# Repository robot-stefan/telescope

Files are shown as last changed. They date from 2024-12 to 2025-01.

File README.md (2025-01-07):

# Telescope
A 3d printed newtonian telescope I designed and built as a personal project. 
Some quick highlights: 
-	the unit features baffling down the optical tube assembly
-	can be printed in the volume of a Prusa MK3S or similarly sized printer
-	is modular in construction allowing for disassembly

> Note: If anyone is interested in a kit or having the prints shipped to them, feel free to contact me and I'll look into pricing. 

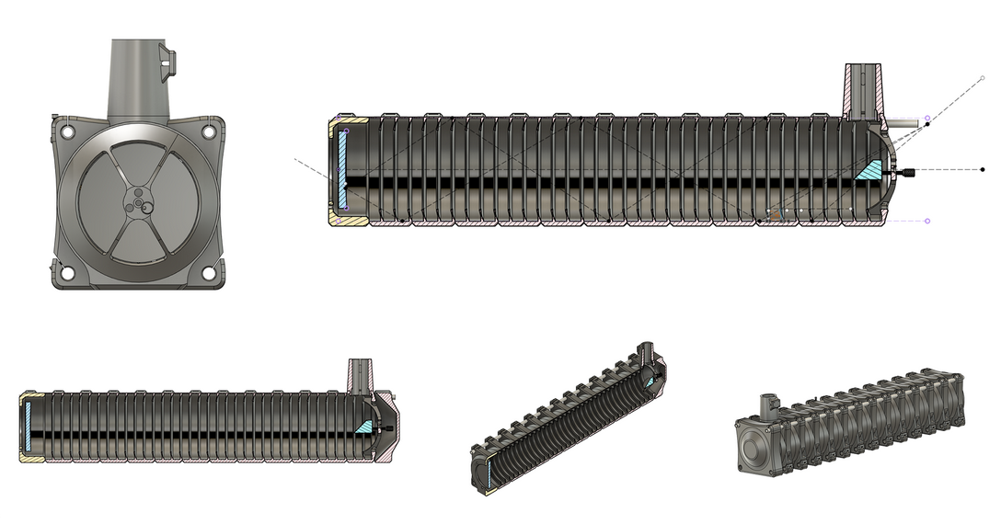
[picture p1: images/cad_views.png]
screenshot_of_various_CAD_views


## Design
Autodesk Fusion 360 was used as the CAD[^CAD] tool and Prusa Slicer served as the CAM[^CAM] tool in the development process. The design was started with 2D high level sketching exploring mirror, lens, and ray paths to drive posistioning of the key parts. Once this phase was completed the structure was iterated on. The slicer acted as a feedback mechanism allowing for the design to be adjusted not only for use, and assembly, but also for ease of printing. Ease of printing in this sense meaning optimizing the filament use of each section so that there is no need to swap out rolls during printing (if starting with a full roll) and that the supports would be easy to remove. It can be noted that depending on a shape a support can take a non-trivial time to remove, and that its removal could also result in damaging the print. Optical components (mirrors, lenses, and mounts) were sourced from Amazon while raw material & hardware from McMaster-Carr. A simple BoM[^BoM] can be found in the [models/README.md](models/README.md).

Flow chart of the Design Process:
```mermaid
graph TD;
    CAD-AutodeskFusion360-->CAM-PrusaSlicer;
    CAM-PrusaSlicer-->CAD-AutodeskFusion360;
    CAM-PrusaSlicer-->3dPrinter;
    Concept-->CAD-AutodeskFusion360;
    3dPrinter-->TestParts;
    TestParts-->CAD-AutodeskFusion360;
    TestParts-->CAM-PrusaSlicer;
    TestParts-->EndPoint;
```

### Baffles
Each cross section is printed with ridges/fingers/ribs. These are baffles and they act to trap stray light rays or reduce the energy in the stray light ray by bouncing it around some before it gets to a person’s eye or a camera / imager. You can see some rough sketches that were turned on where ray tracing was done manually to find a good enough configuration in the below image. 

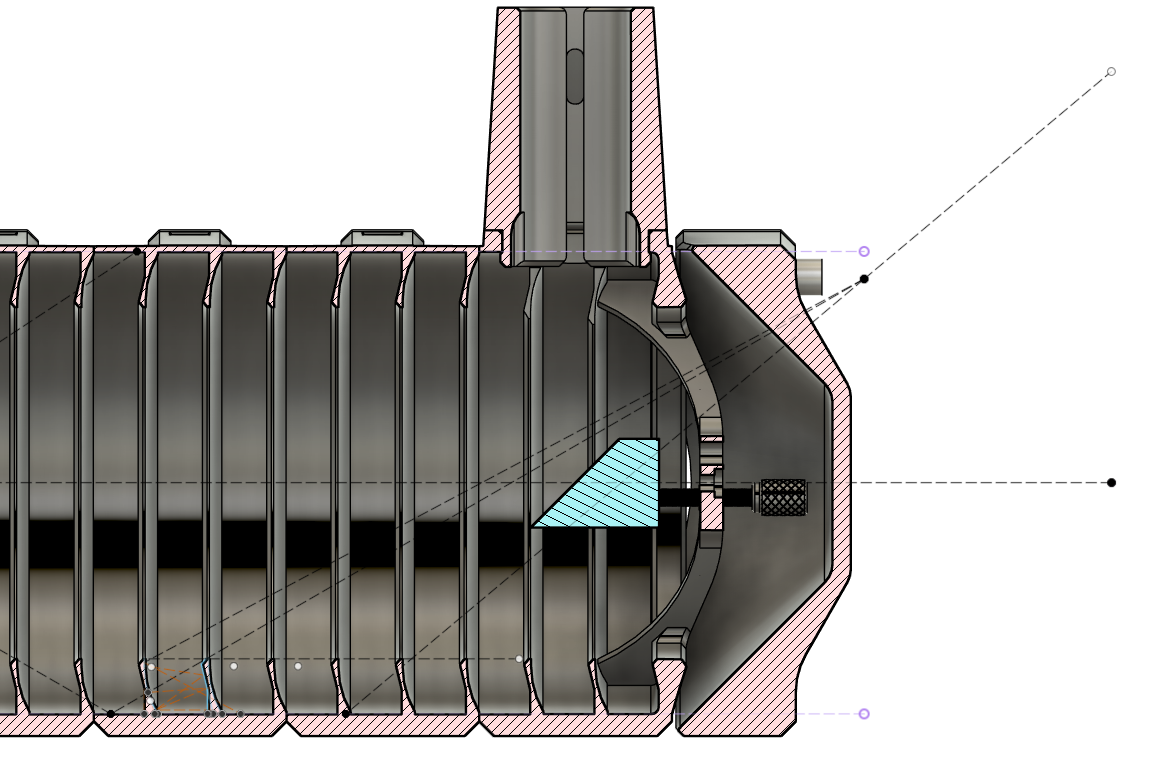
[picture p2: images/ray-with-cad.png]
image_of_manual_raytrace


These rays could come from artificial light sources and other sources that might impact image quality. Telescope builds in this size class are typically done with plain cardboard tubes which are then coated with a matte black paint. The approach lowers the amount of reflected energy, but depending on the ray incident with the tube wall light may only have one or two bounces. Since this was 3D printed, I had the ability to go beyond a plain tube and add additional complexity in the form of baffling. These baffles function to trap rays giving them 2 or more bounces before leaving the baffle reducing ray energy. Ideally these baffles would also be coated with a low reflective paint for added performance. If one were to fully optimize the baffles these features would change spacing and geometry (curve profile) through the length of the tube assembly [^MERTIS]. However, to keep the part variation low, all tube cross sections (except for the front and rear) are the same. As I am located in a urban area baffleing can mitigate nearish light sources such as street lights, flashlights, illumination from mobile devices, and automotive sources. A closer look at the baffles can be found in [analysis/README.md](analysis/README.md).

### Printing
The parts are printed with less supports that normally seen due to tweaks in geometry[^FdmDesignGuide]. Supports were manually added in a few spots. The telescope was constrained in size by what I could fit standing up on the printer. All sections (except for the eye piece are a single print). The eye piece end is printed in two parts and bonded together.  Removing the tube and having it glued in allowed for build test and design iterations that did not need to wait on an 18 hr print, also reduced filament consumption, and allowed for test prints in between the batch prints of the other sections. The tube which holds the eye piece required some iterations to get the right amount of friction in the adjustment for the eye piece. 
Very low gyroid infills were used and supports were manually added to improve support removal and print time. 

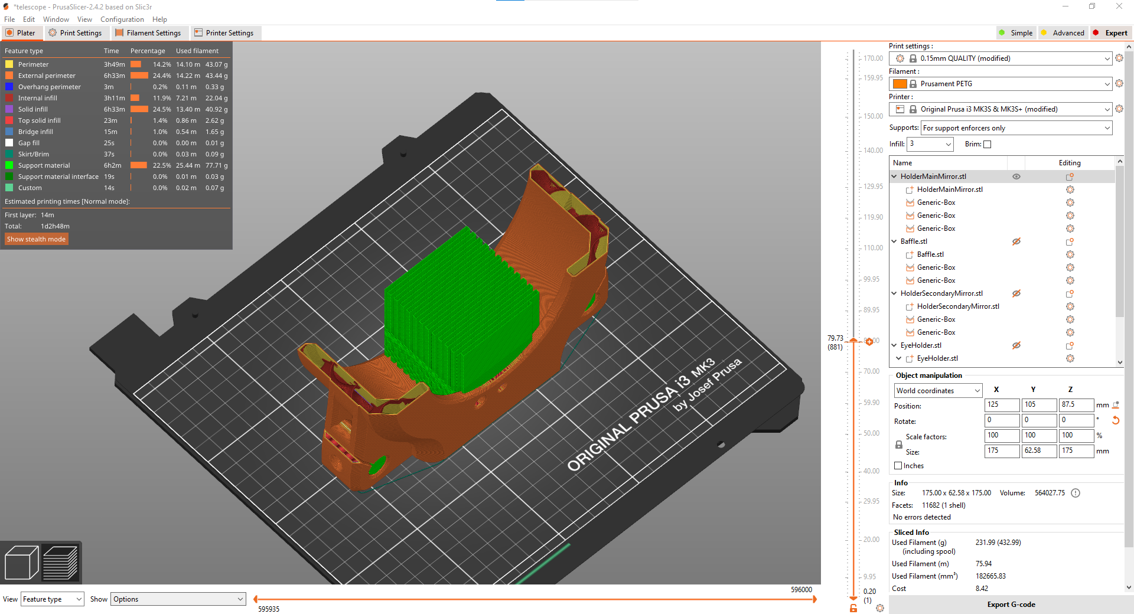
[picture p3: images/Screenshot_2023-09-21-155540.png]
screenshot_of_prusa_slicer


## Disassembly & Reassembly 
One of the driving goals of the modularity was to allow the unit to be broken down to fit with in the standard airline checked luggage size limit (with the optics being carry on). The closest darksies with minimal treecover are all west of the Mississippi River[^DarkSkyMap]. Theses sites would necessitate a long road trip or flying. 
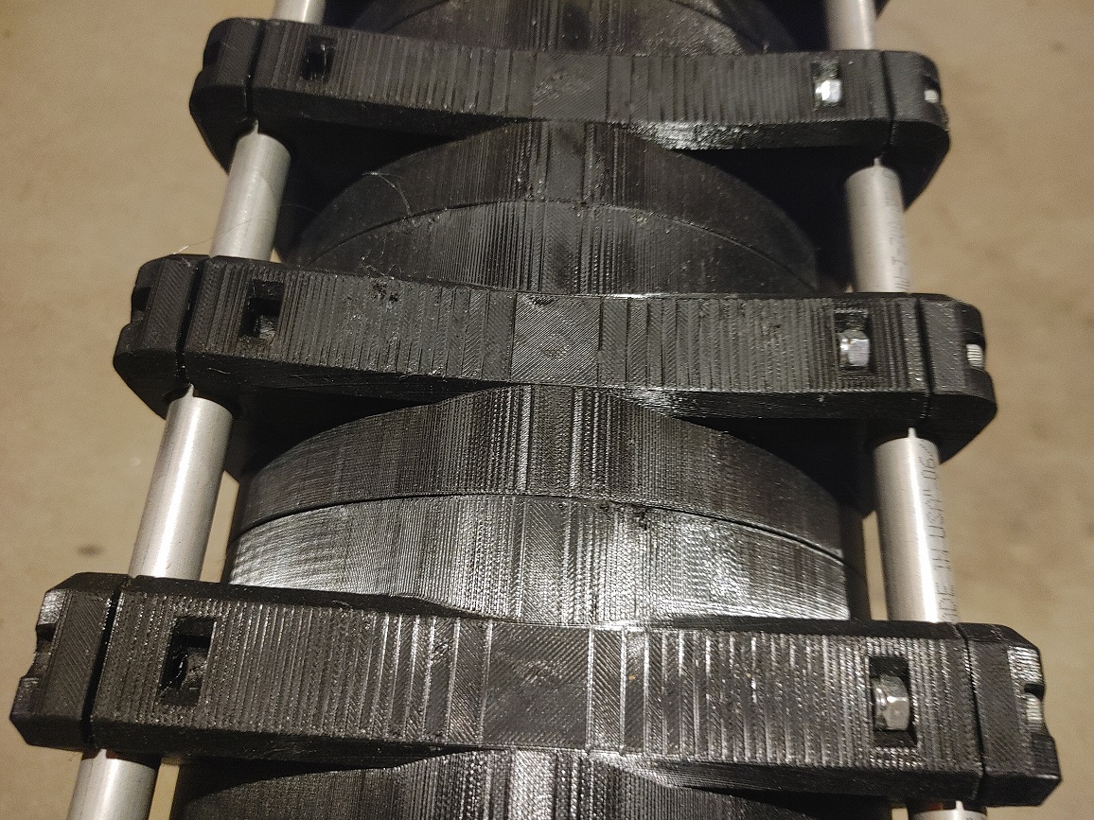
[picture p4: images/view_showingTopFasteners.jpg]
view_of_top_fasteners

For assembly and dissassembly time not all locations for fastners were utilized. It was found that the pockets for the nuts were a bit thin. Switching to non nylocs or thicker walls in these regions would remedy this. 

## Using the Telescope
### First Light
Some of the 1st images captured with a cell phone and camera mount. More work can be done to improve this such as getting an imager board and more ridigly mounting a camera to the scope. Currently taking photos of stars is not possible. The picture of jupiter is a near best case of these results using a smart phone camera. The COTS phone mount I found is not good enough for sufficently large cell phones. A fair bit of detail can be seen with the eye including a few of the moons of jupiter. The below photos were taken in suburban metro Atlanta, GA. 

| Jupiter | Moon 1 | Moon 2 |
| :---: | :---: | :---: |
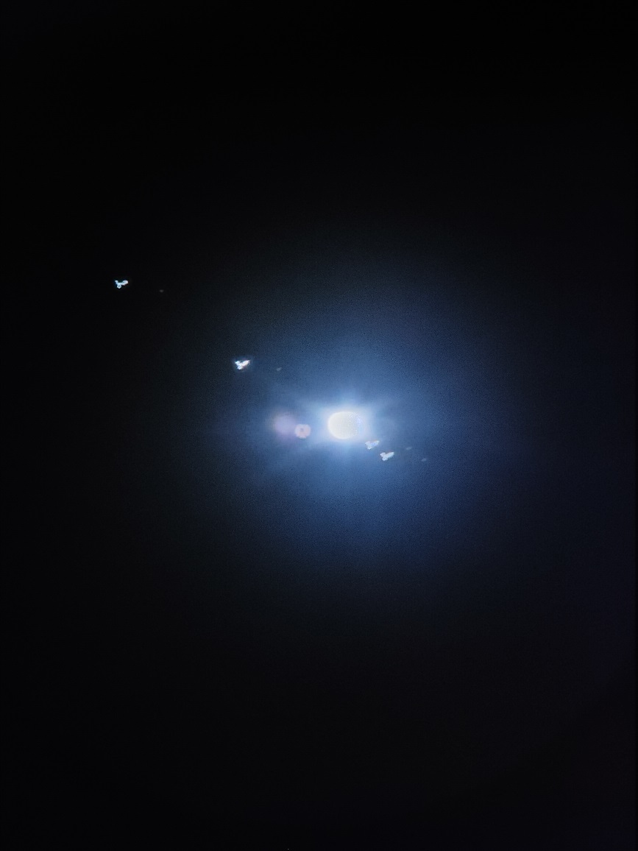
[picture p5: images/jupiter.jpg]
image_of_jupiter
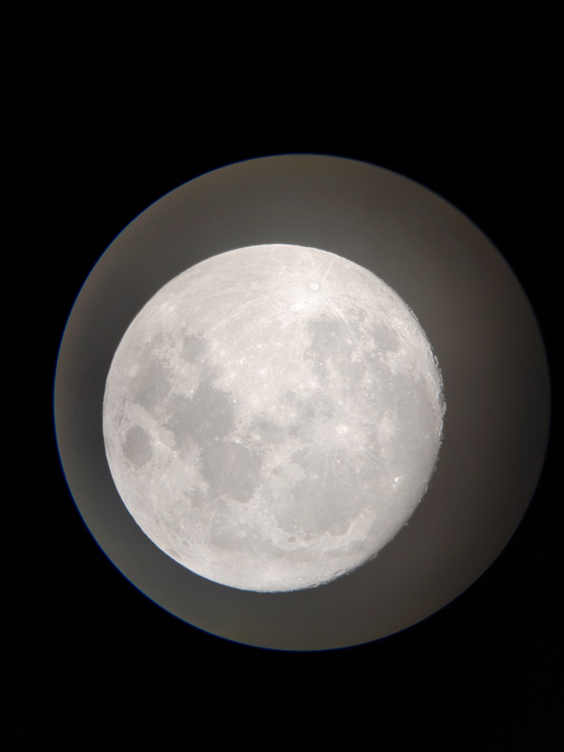
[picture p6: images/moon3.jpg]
image_of_moon
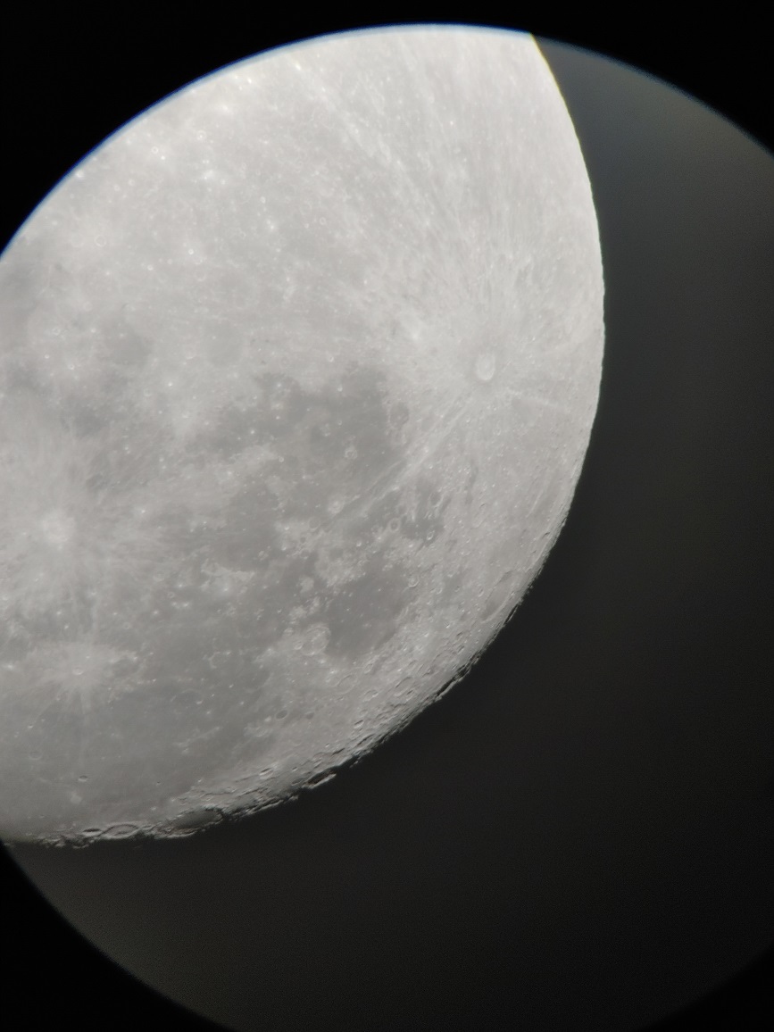
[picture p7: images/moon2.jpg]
image_of_moon
|  |  |  |

At present the unit does not have a finder scope to aim to help with aiming. The inward curved sides can be used with some success to aim at targets. This along with the cell phone mounting is a current short coming of the system. A finder scope may be added in the future. The rails running along each corner were exposed in the design to allow for adding attachments. The adapter to attach to a tripod was connected to the telescope with the rails. 

### Camping Trip
I was able to do a camping trip out to Camanche National Grasslands[^Comanche] as part of road trip to Denver for a trade show. A number of sites in the grasslands feature very dark skies and minimal tree or tall terrain features providing a near unobstructed full 360 degree view of the sky in some of the darkest areas of the continental United States. No photos from the scope exist due to issues with the COTS phone mount. 

| Deploying System | Image of Sky | Telescope Setup @ Night |
| :---: | :---: | :---: |
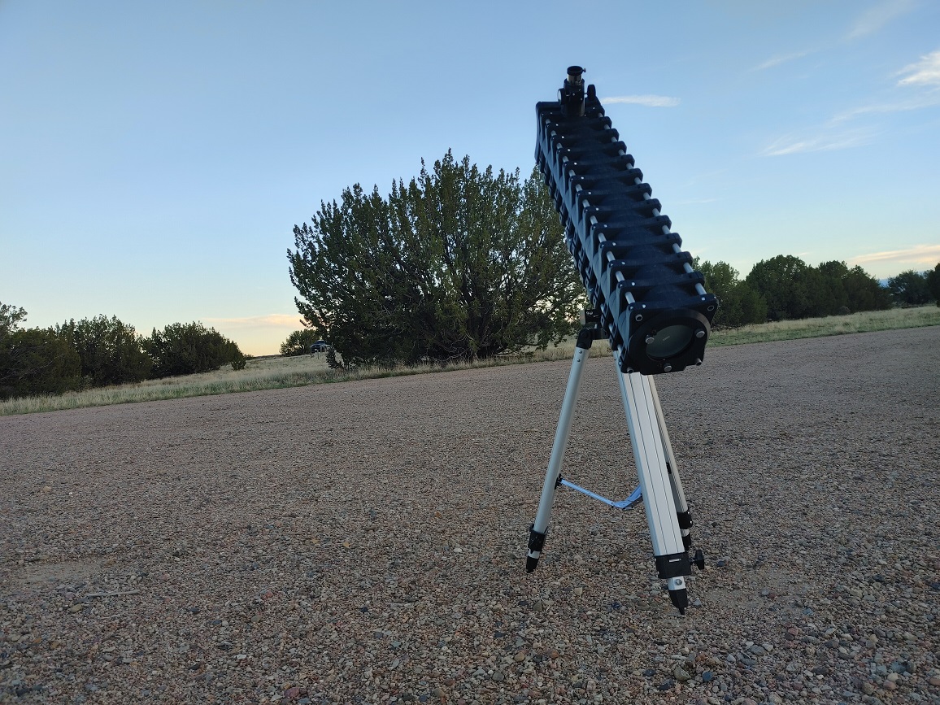
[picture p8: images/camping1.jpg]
image_of_camping_setup_in_daylight
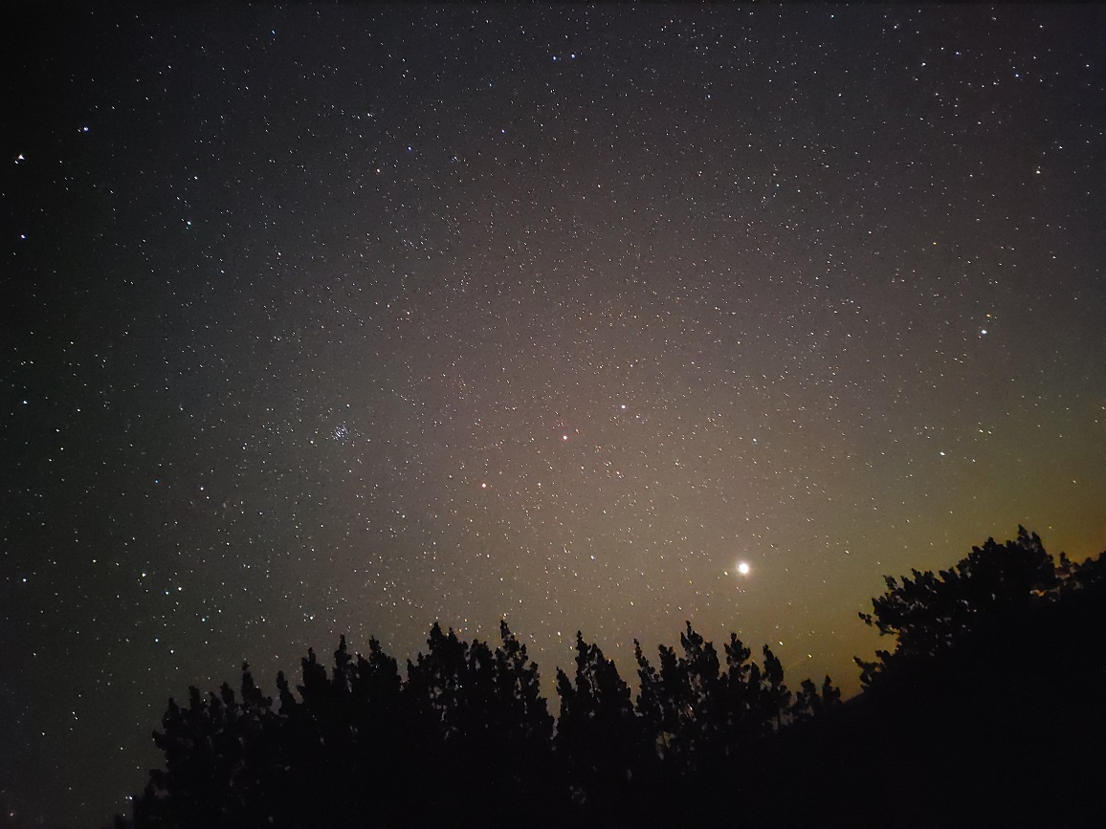
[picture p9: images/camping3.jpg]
image_of_sky
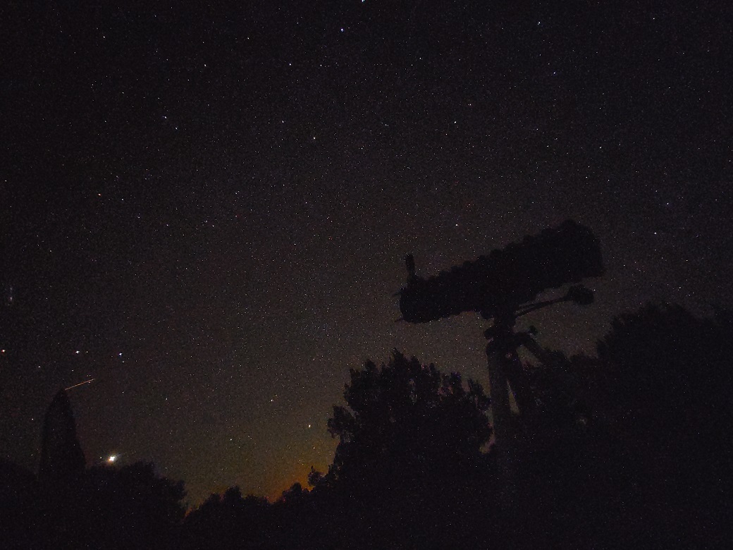
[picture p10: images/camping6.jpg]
image_of_telesope at night
|  |  |  |

[^CAD]: CAD = Computer Aided Design 
[^CAM]: CAM = Computer Aided Machining / Manufacturing
[^BoM]: BoM = Bill of Materials
[^MERTIS]: [MERTIS - Reflective baffle design and manufacturing](https://www.nicoform.com/Images_Content/Site1/Files/Articles/MERTISReflectiveBaffleDesign.pdf)
[^DarkSkyMap]: [Dark Sky Map](https://www.darkskymap.com/)
[^Comanche]: [Comanche National Grasslands](https://www.fs.usda.gov/recarea/psicc/recarea/?recid=12409)
[^FdmDesignGuide]: [FDM 3d Printing Design Guide](https://www.hubs.com/knowledge-base/how-design-parts-fdm-3d-printing/)

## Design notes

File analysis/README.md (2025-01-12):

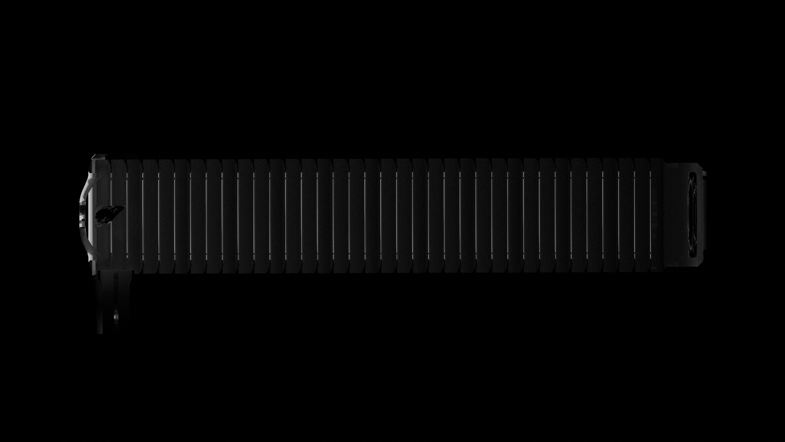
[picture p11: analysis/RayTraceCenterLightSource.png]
image_of_raytrace_OLF_B


In the overview it was mentioend that the baffle design was done with manual geometric ray tracing in the top level sketches of the cad file. The overall approach was inspire by the MERTIS paper (ref is in the primary README). There are limitations to the manual approach, but how good or good enough is it? 

While opensource ray tracing and optics design tools are not as well polished as commercial tools such as tracepro and zemax, there are options to look at the baffle design with ray tracing found in opensource rendering software. This approach can give us a comparison, but cannot give us exact info such as an easy way to observe the path of rays, energy in the rays, or a route to numerically compare the results. A qualitative and some what subjective approach can be attempted with tools such as Blender[^1] and LuxCoreRender[^2]. 

Blender 4.2 and BlendLuxCore 2.9 were used on windows to conduct this comparison. The render time was fixed and plain tube was swapped out the baffle sections. Material properties with a matte finish and lighting setup was kept the same so that the only variable in each is the geometry. The secondary mirror was also turned off.

| Setup | Baffle | Plain |
| :---: | :---: | :---: |
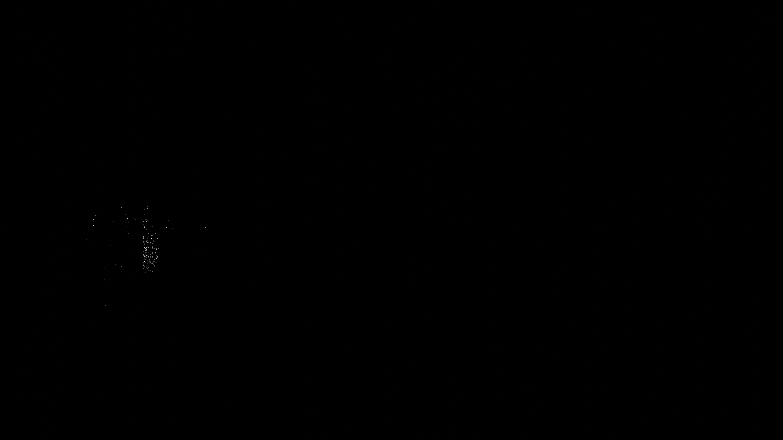
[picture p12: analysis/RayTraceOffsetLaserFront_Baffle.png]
image_of_raytrace_OLF_B
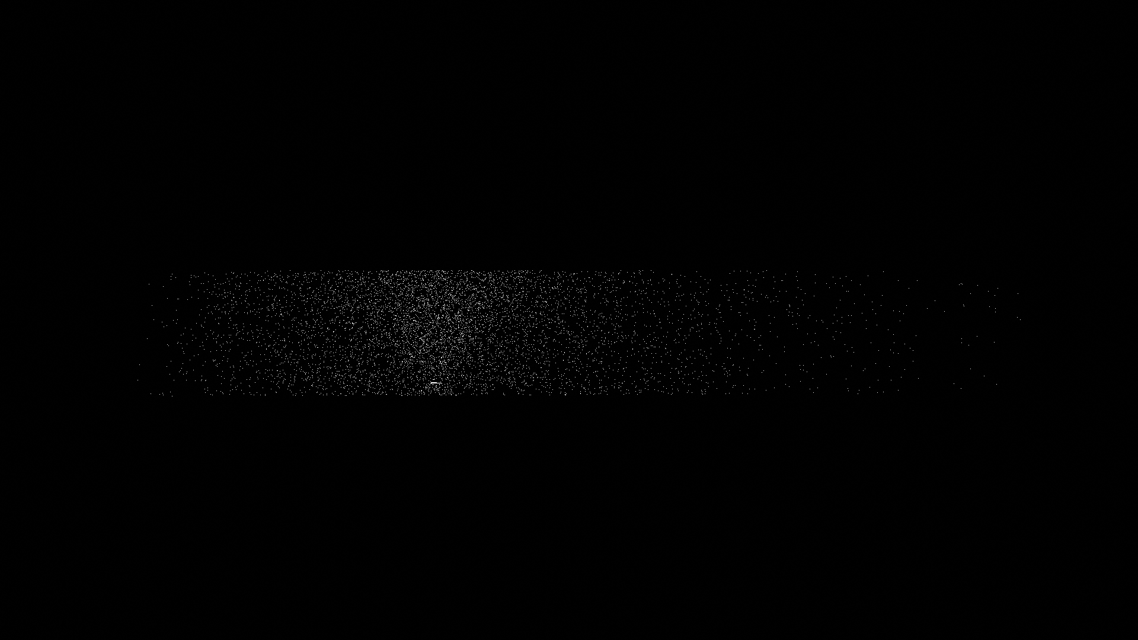
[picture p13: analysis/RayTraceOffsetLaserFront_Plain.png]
image_of_raytrace_OLF_P
| Offset Laser Front |  |  |
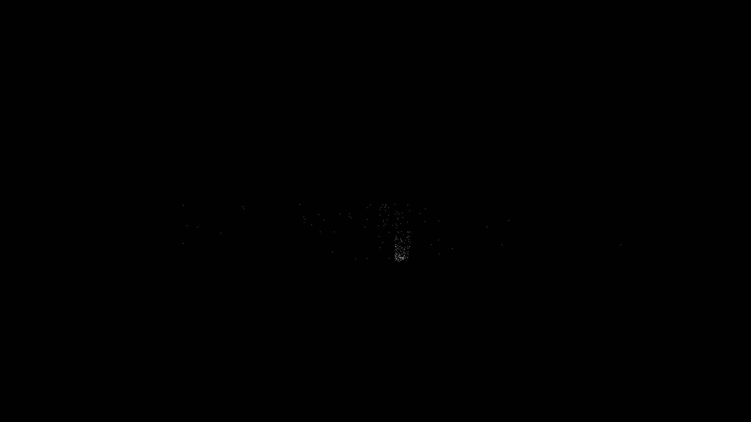
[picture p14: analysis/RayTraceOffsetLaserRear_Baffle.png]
image_of_raytrace_OLR_B
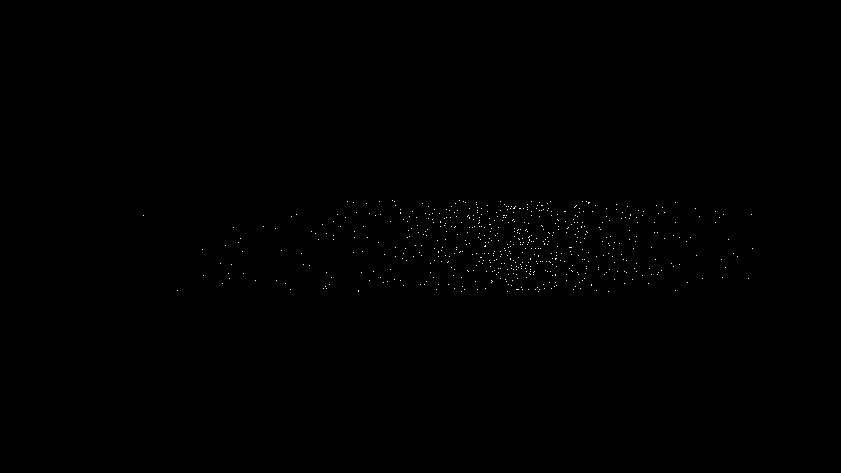
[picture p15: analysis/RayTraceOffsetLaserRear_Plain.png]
image_of_raytrace_OLR_P
| Offset Laser Rear | |  |
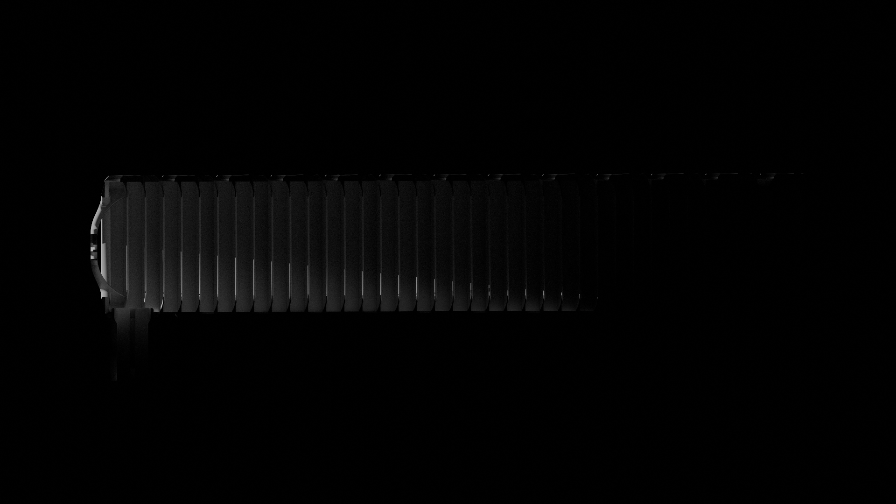
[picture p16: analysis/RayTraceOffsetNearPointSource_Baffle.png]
image_of_raytrace_ONPS_B
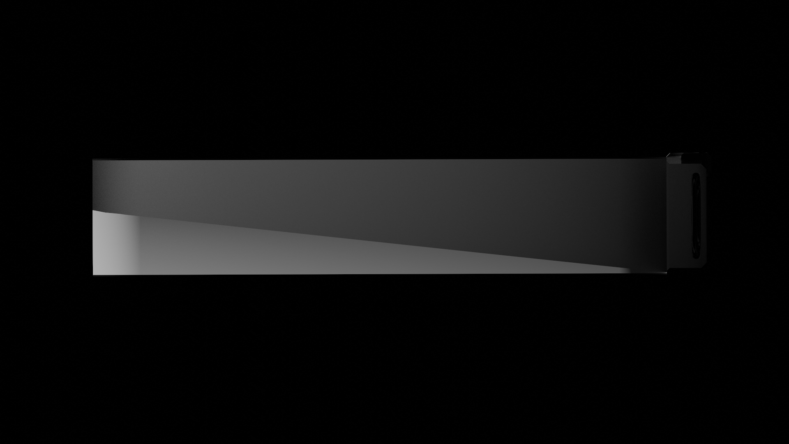
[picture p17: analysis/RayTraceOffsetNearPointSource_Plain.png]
image_of_raytrace_ONPS_P
| Offset Point Near|  |  |
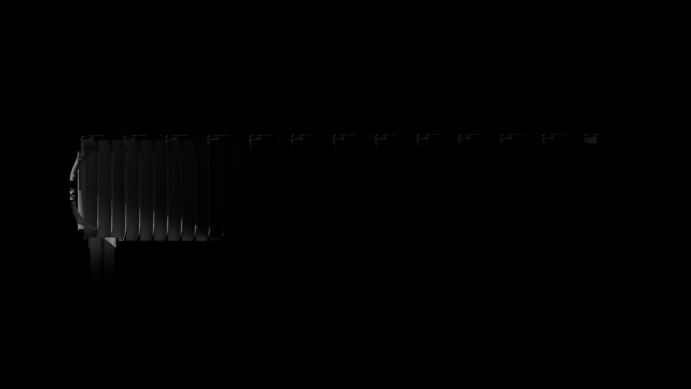
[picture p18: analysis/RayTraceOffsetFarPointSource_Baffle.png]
image_of_raytrace_OFPS_B
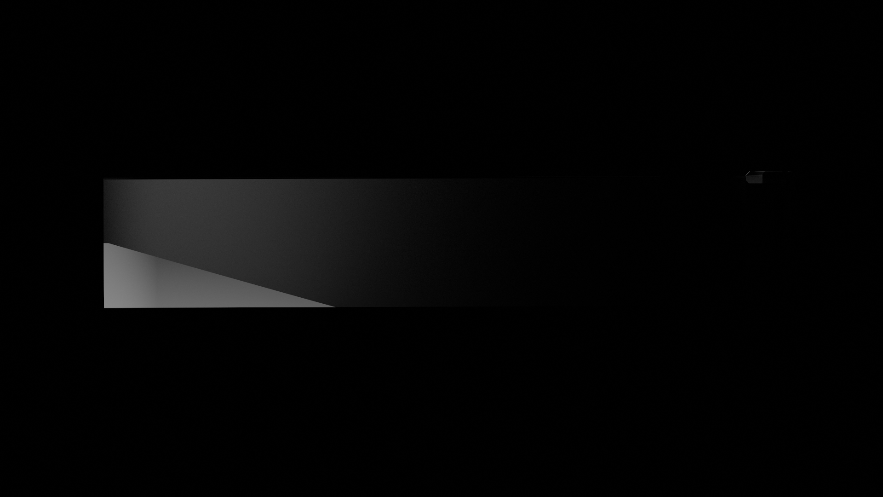
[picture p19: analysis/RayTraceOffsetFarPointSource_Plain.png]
image_of_raytrace_OFPS_P
| Offset Point Far|  |  |

Looking at the two laser setups we can see that the baffles do appear to be trapping reflections as generally intended compared to the tube. For the offset point sources we can also observe that the baffled tube seems to be greatly reducing the light energy that gets down toward the primary mirror compared to the plain tube. Thus reducing stray light rays getting to the eye piece. One area of improvement can be somewhat observed in the offset point renderings. A hood, shade, shroud mounted to the front posts during use may reduce rays in the eyepiece tube area some. This front region is where the storage cover sits when the telescope is not being used so there is space to experiment.

The approach while somewhat helpful has limitations and cannot readily answer more in-depth questions such as:
1. How beneficial would adding a matte coating to the baffle be?
2. What trade offs would different coatings present?
3. Could the baffle benefit from simple geometric adjustments? 
4. When light does make it the eyepiece how much energy does it have?

The 4th question has some relevance, if we were to put an imager at the eyepiece knowing something about the energy of stray rays might help us understand if that energy gets lost in the noise of the imager or if it is comparable to stars. However most of the imagers in the DIY / hobbyist realm aren't necessarily going to have exceptional low light performance and the population to select from isn't as varied.  

Other tools such as ray-optics[^3] and possibly solvers for openFOAM[^4] such as laserbeamFOAM may also present a way to investigate the baffled tube further. Files for both a [python script](PythonRayopticsTelescope.py) and a [jupyter notebook](PythonRayopticsTelescope.ipynb) using ray-optics are included. Each allows for investigating the layout and fundamental setup of the telescope, but not the baffles.     

[^1]: [Blender](https://www.blender.org)
[^2]: [LuxCoreRender](https://luxcorerender.org/)
[^3]: [ray-optics](https://github.com/mjhoptics/ray-optics)
[^4]: [openFOAM](https://openfoam.org/)

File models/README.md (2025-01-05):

This models fodler contains step, stl, and the 3mf file used to slice and generate gcode. Below are notes for these files and Primitive Bill of Materials. 

STL Files:
- ASCI
- units = mm

STEP Files:
- ASCI

telescope.3mf:
- Created by Prusa Slicer in 2022
- For a Prusa MK3S

Optics:
- Mirror Primary = 120 mm diameter & 1000 mm focal length
- Mirror Secondary =  37 mm x 27 mm
- Mirror Note - Primary & Secondary were a kit from amazon (B08VLTLQCH) from Cosmo Brands[^MirrorKit]
- Eye Piece - 8 mm to 24 mm Celestron 93230 (B0007UQNV8)
- Barlow 2x - Celestron 93326 (B00008Y0TM)
- Collimator - SVBONY Red Laser Collimator (B00LX34ZH2) 

Printed Parts
- Baffle  (x11)
- EyeHolder (x1)
- EyePieceAdjusterCover (x1)
- EndCover (x1)
- HolderMainMirro (x1)
- HolderSecondaryEyePiece (x1)
- MountAdapterBody (x1)
- MountAdapterClamp (x8)

Other Purchased Mechanical:
- Eye Piece Focus Housing = 1.25 in for 117 mm to 140 mm optical tube (B08XLHQ22T) from Cosmo Brands [^EyePieceFocus]
- Tripod - Celestron 93607 Heavy Duty Alt-Azimuth Tripod (B0007UQNY0)
- Metal Tube - Al 6061 1/2 in OD x 0.049 in wall (McMaster-Carr 9056K65)
- Fastener - SHCS - 8-32 x 1 in (McMaster-Carr 90128A199) (x68) [^FastenerNote]
- Fastener - Nyloc - 8-32 (McMaster-Carr 90631A009) (x68) [^FastenerNote]
- Fastener - SHCS - 4-40 x 3/8 in (McMaster-Carr 95868A258) (x4)
- Adjustment Screws - 1/4-80 (McMaster-Carr 97424A620)
- Heat Insert - M5 x 0.8 mm (McMaster-Carr 94180A361) (for primary mirror other fastener harware was reused)
- Heat Insert - 4-40 (McMaster-Carr 93365A120) (x4)
- Heat Insert - 1/4-20 (McMaster-Carr 93365A162) (x1) (for tripod mount adapter)
- Insert  - 1/4-80 (McMaster-Carr 98625A950) (x3) [^80TPI]
- Filament - Makeshaper Black PETG

Key Tools:
- 3d Printer (Prusa MK3S)
- Hex key set (Home Depot HLAHKSM26PC)
- Iron (Weller WLC100 | B000AS28UC)
- Heat insert tips (92160A131,	92160A123, 92160A119)

Procurment:
- I had good success with many of the amazon warehouse / used options particularly for the Celestron branded parts. 
- B######## Are the amazon ASIN numbers. You will also see them in the URL and they can be pasted into the search box.

[^MirrorKit]: These nolonger seem to be available. As such the primary mirror holder and secondary may need to be modified for a different kit or addtional parts may be needed to mount other mirrors since parts from the kit were utilized.  
[^EyePieceFocus]: This part was dissassembled and portions of it were used.
[^FastenerNote]: Only around 1/2 were used during build up.
[^80TPI]: Not a heat or press fit. These slide in. If you end up using glue in your print only use a small amount. Glue wicking into an 80 thread per inch thread will prevent function.

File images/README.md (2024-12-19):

This directory contains sample images showing design and use of the telescope.

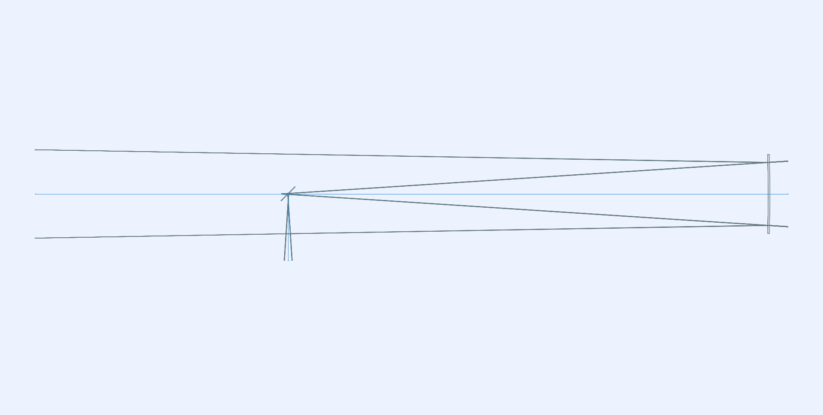
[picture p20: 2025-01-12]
analysis/PythonRayopticsTelescopeFigure01.png

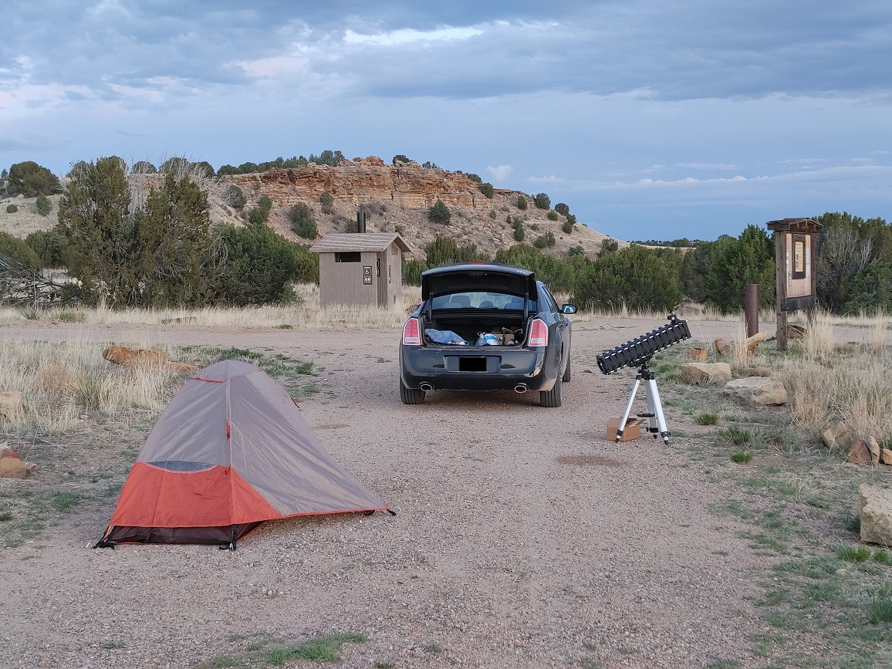
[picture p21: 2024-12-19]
images/camping4.jpg

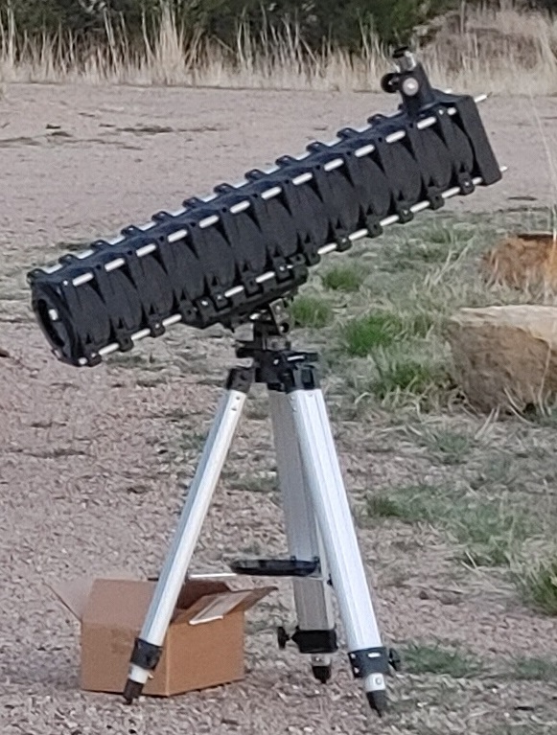
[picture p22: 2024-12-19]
images/camping5.jpg

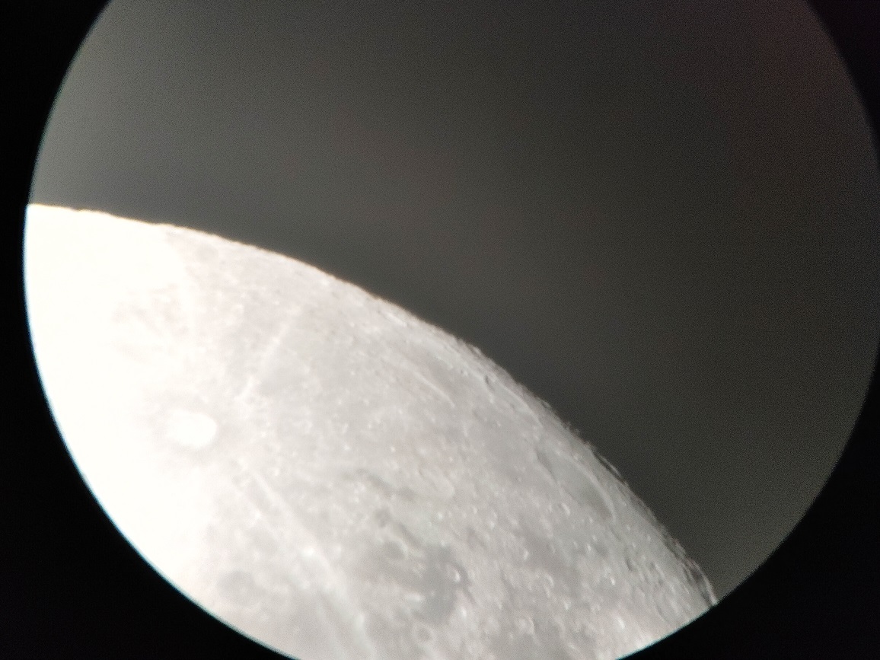
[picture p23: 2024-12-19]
images/moon1.jpg

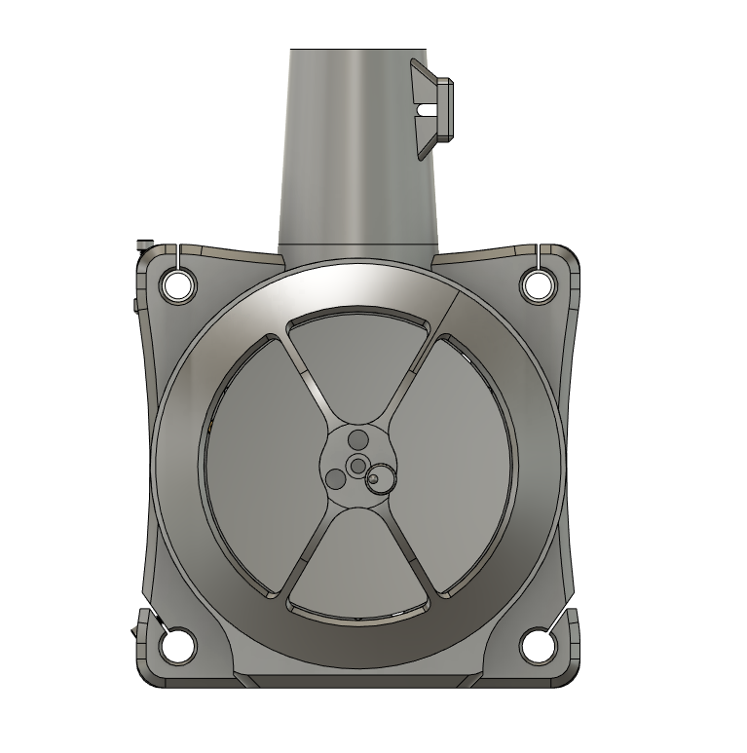
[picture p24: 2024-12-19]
images/Screenshot_2023-09-21-155145.png

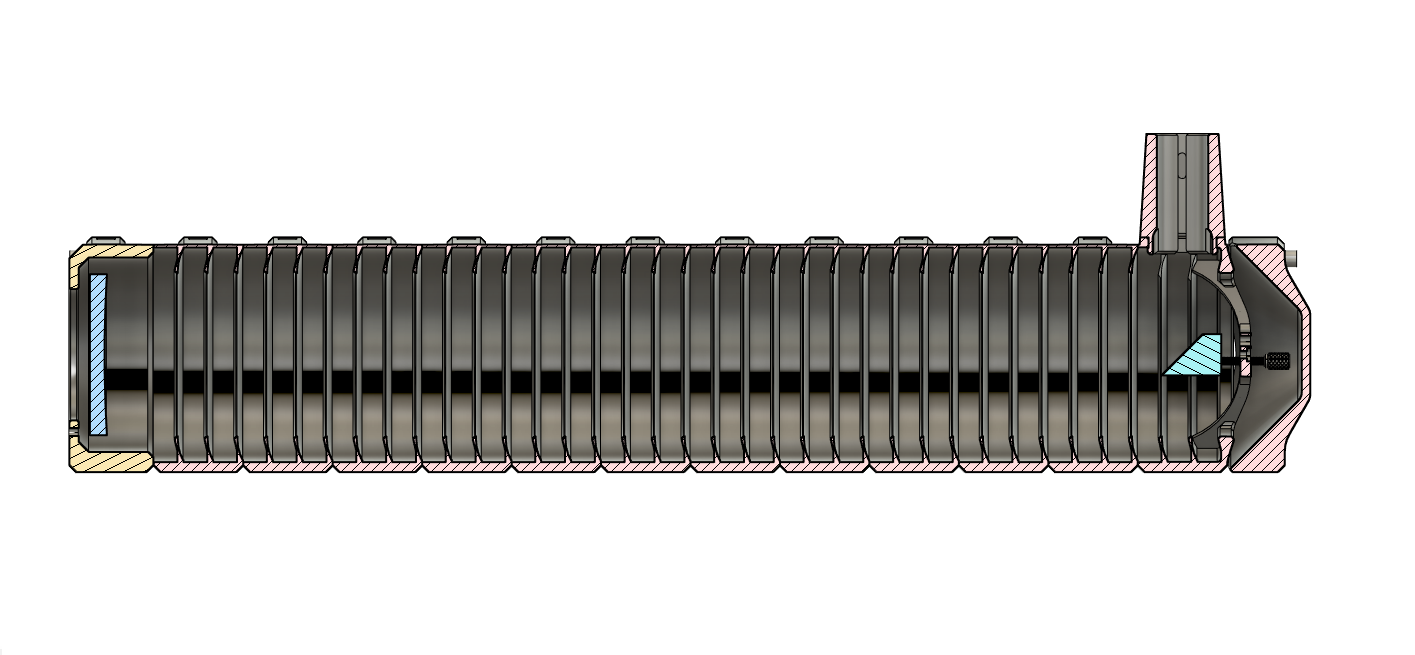
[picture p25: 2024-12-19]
images/Screenshot_2023-09-21-154956.png

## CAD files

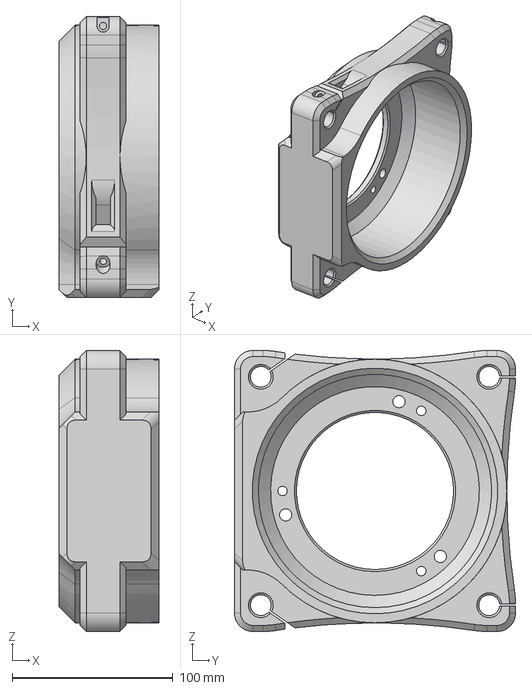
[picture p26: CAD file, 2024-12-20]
models/HolderMainMirror.step
62.6 x 175.0 x 175.0 mm

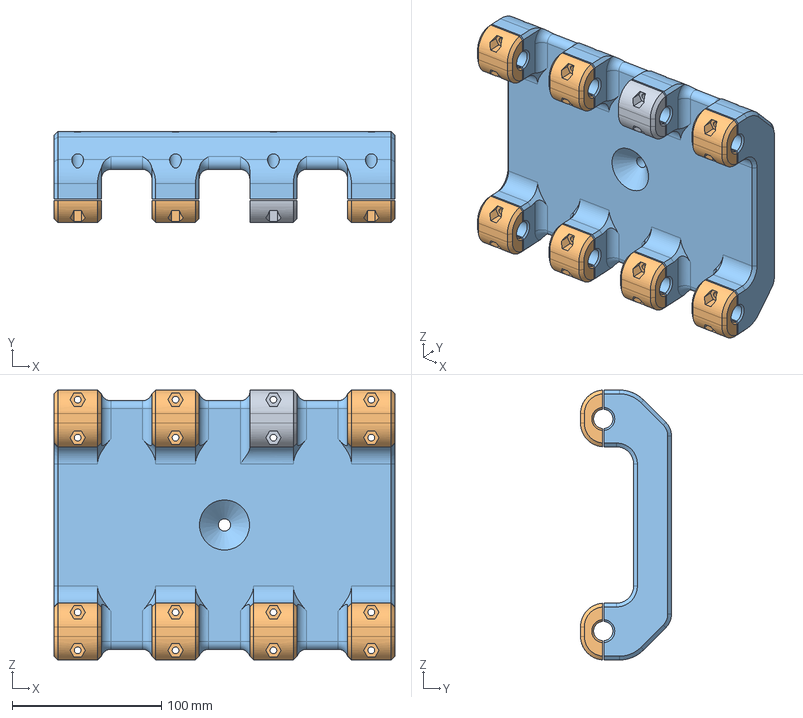
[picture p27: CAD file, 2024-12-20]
models/MountAdapter.step
228.6 x 61.0 x 181.0 mm

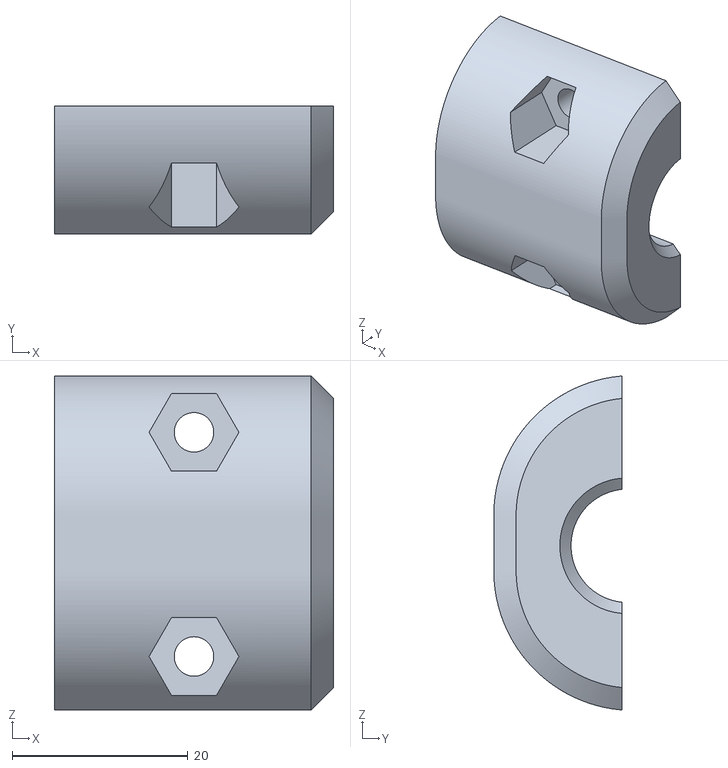
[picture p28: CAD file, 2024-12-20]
models/MountAdapterClamp.stl
31.7 x 14.6 x 38.0

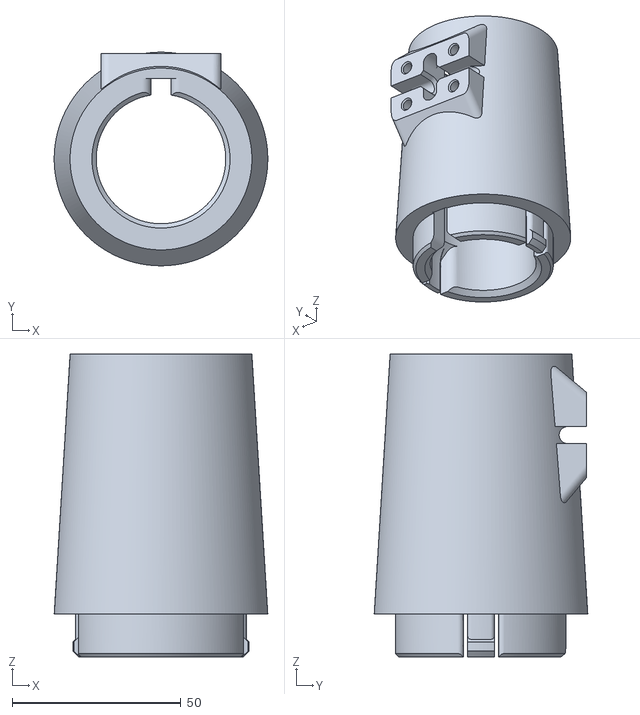
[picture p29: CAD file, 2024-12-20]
models/EyeHolder.stl
63.2 x 63.2 x 89.7

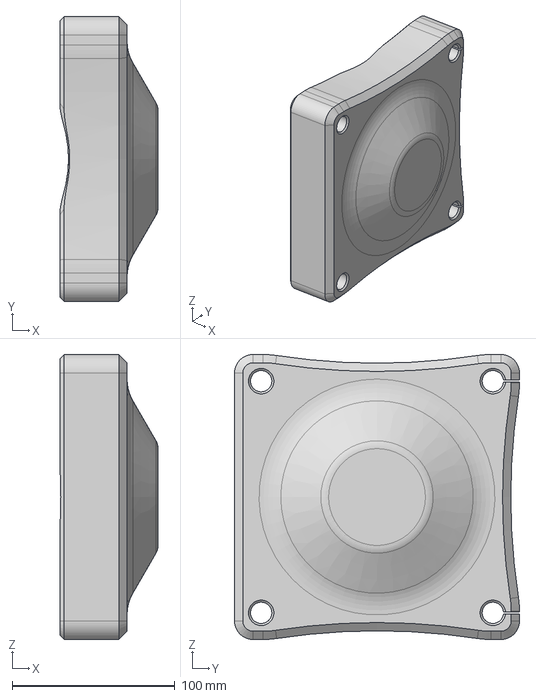
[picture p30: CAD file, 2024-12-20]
models/EndCover.step
60.3 x 175.0 x 175.0 mm

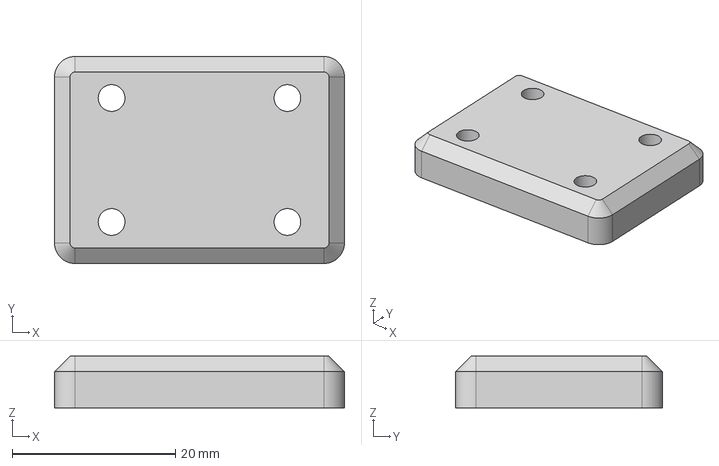
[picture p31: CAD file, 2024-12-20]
models/EyePieceAdjusterCover.step
35.6 x 25.4 x 6.35 mm

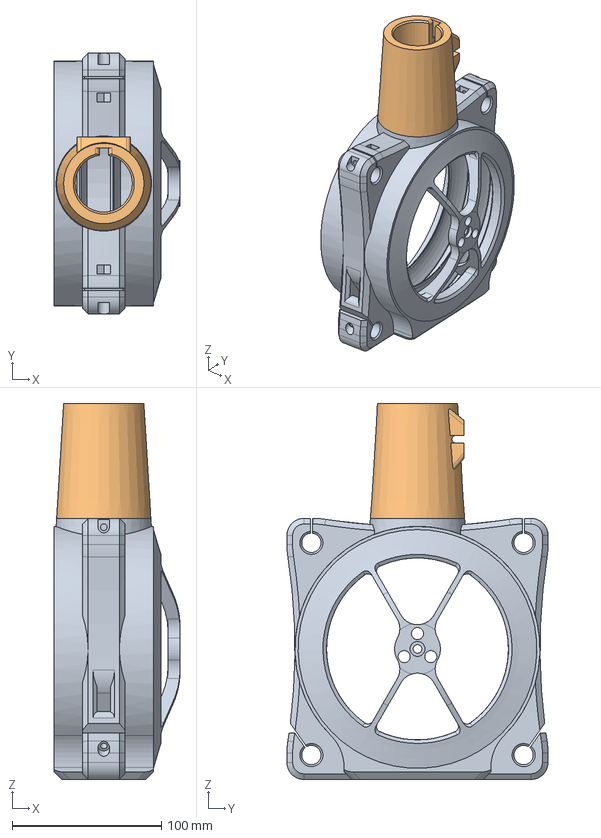
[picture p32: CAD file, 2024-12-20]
models/HolderSecondaryEyePiece.step
84.4 x 175.0 x 252.0 mm

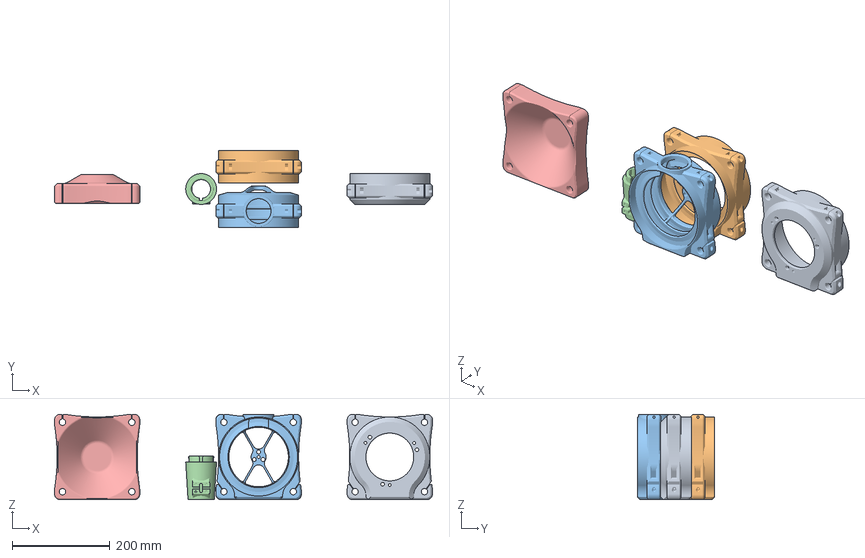
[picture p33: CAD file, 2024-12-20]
models/telescope.3mf
775.0 x 157.1 x 175.0 mm
HolderMainMirror.stl
Baffle.stl
HolderSecondaryMirror.stl
EyeHolder.stl
EndCover.stl

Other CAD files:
models/Baffle.step
models/EndCover.stl
models/EyePieceAdjusterCover.stl
models/HolderMainMirror.stl

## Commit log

2024-12-19 Add files via upload
    added image showing various cad views
2024-12-20 Add files via upload
    Added models
    [Baffle.step, EndCover.step, EyePieceAdjusterCover.step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]
2024-12-20 Add files via upload
    added stl files
    [EndCover.stl, EyeHolder.stl, EyePeiceAdjusterCover.stl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]
2025-01-03 reuploaded fixed spelling
    [EyePieceAdjusterCover.stl]
2025-01-03 Update README.md additional info showing assembly and design
2025-01-04 Update README.md corrected 80 tpi insert note.
2025-01-04 Add files via upload
    added image files comparing baffle tube to plain tube
